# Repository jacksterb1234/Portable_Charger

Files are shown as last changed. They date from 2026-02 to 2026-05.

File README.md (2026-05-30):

# Portable Charger — USB-C Power Delivery PCB

A custom portable USB-C Power Delivery (PD) charger with a dedicated PD trigger circuit for negotiating output voltage. Powered from a single USB-C input and designed for compact, portable use.

## Features

- **USB-C Power Delivery** input with PD voltage negotiation trigger
- **Custom PD trigger circuit** to request a specific voltage from the source
- Compact KiCad PCB design optimized for portability
- Designed with **JLCPCB assembly** constraints in mind
- CAD enclosure files included

## Repository Structure

```
Portable_Charger/
├── Charger_Kicad/         # Main charger PCB KiCad project
├── USBC_PD_Trigger_Kicad/ # USB-C PD trigger board KiCad project
└── CAD/                   # Enclosure / mechanical CAD files
```

## How It Works

1. The **PD trigger board** negotiates a target voltage with a USB-C PD source using the CC lines
2. The negotiated voltage is passed to the **charger board** for regulation and output
3. The design runs entirely from a single USB-C cable — no barrel jacks or separate power supplies required

## Tools Used

- **KiCad** — Schematic capture and PCB layout
- **JLCPCB** — PCB fabrication and assembly
- **Fusion360 / SolidWorks** — Enclosure design

## Author

**Jackson Barber** — [github.com/jacksterb1234](https://github.com/jacksterb1234)

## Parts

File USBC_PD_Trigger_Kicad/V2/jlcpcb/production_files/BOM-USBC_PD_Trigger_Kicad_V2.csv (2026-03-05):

Comment | Designator | Footprint | LCSC | Quantity
100nF | C1,C5,C8 | C_0805 | C28233 | 3
10kΩ | R10,R6,R8 | R_0805 | C17414 | 3
10nF | C9 | C_0805 | C1710 | 1
10uF | C12,C13,C2 | C_0805 | C15850 | 3
1uF | C10,C4 | C_0805 | C28323 | 2
200kΩ | R9 | R_0805 | C17539 | 1
22uF | C3 | C_0805 | C45783 | 1
300Ω | R11,R12,R13,R14 | R_0805 | C17617 | 4
4.7kΩ | R1,R2,R3,RPA0 | R_0805 | C17673 | 4
4.7uF | C11 | C_0805 | C1779 | 1
470pF | C6,C7 | C_0805 | C1743 | 2
8.2kΩ | R7 | R_0805 | C17828 | 1
ATtiny816-S | U4 | SOIC-20W_7.5x12.8mm_P1.27mm | C2054204 | 1
FUSB302BMPX | U1 | WQFN-14-1EP_2.5x2.5mm_P0.5mm_EP1.45x1.45mm | C132291 | 1
HT7533 | U2 | SOT-89-3_L4.5-W2.5-P1.50-LS4.2-BR | C14289 | 1
LED | D5 | LED_0805_2012Metric | C2297 | 1
LS2406ERQ23 | U3 | QFN16L_2P5X3P2-0P6_LTF | C5355481 | 1
Screw_Terminal_01x02 | J2 | TerminalBlock_RND_205-00045_1x02_P5.00mm_Horizontal | C3703 | 1
Tactile Button, 160gf | S1 | SW_TS-1088-AR02016 | C720477 | 1
USB_C_Receptacle_PowerOnly_6P | J1 | USB_C_Receptacle_GCT_USB4125-xx-x-0190_6P_TopMnt_Horizontal | C7507406 | 1
Conn_01x03_Pin | J3 | PinHeader_1x03_P2.54mm_Vertical |  | 1
LED | D7 | LED_0805_2012Metric |  | 1
LED | D8 | LED_0805_2012Metric |  | 1
LED | D6 | LED_0805_2012Metric |  | 1

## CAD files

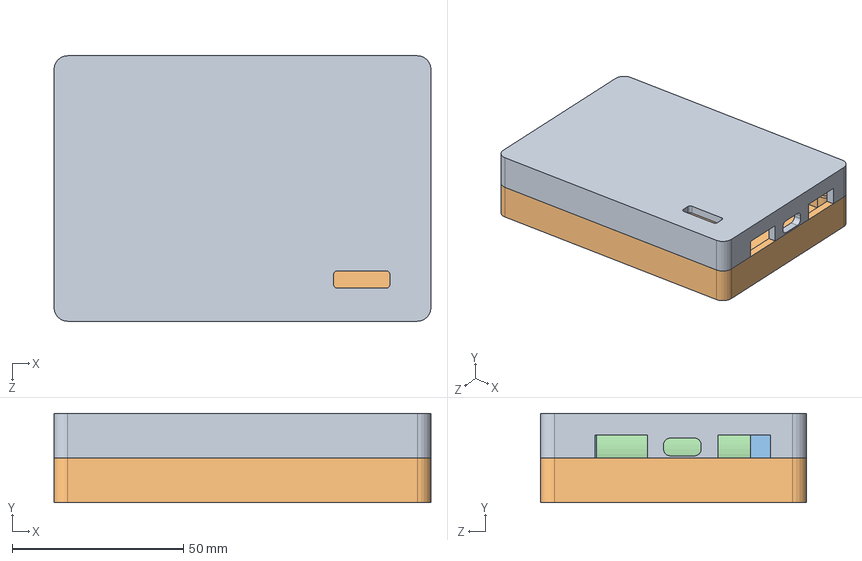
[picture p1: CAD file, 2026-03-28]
CAD/Charger_Main.SLDASM
110.0 x 26.0 x 77.5 mm
Battery_Cell x 3
6S_Battery_Holder x 2
Charger_Case
Charger_Case_Top

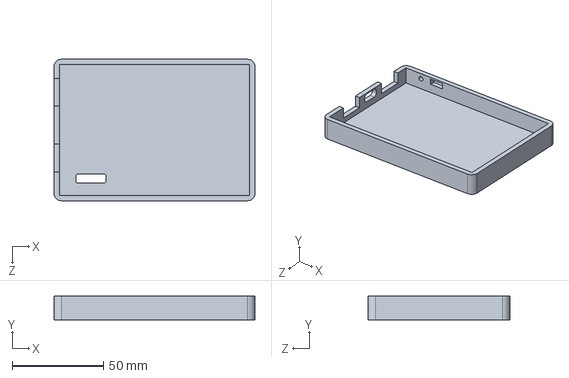
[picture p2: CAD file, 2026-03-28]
CAD/Charger_Case_Top.SLDPRT
110.0 x 13.0 x 77.5 mm

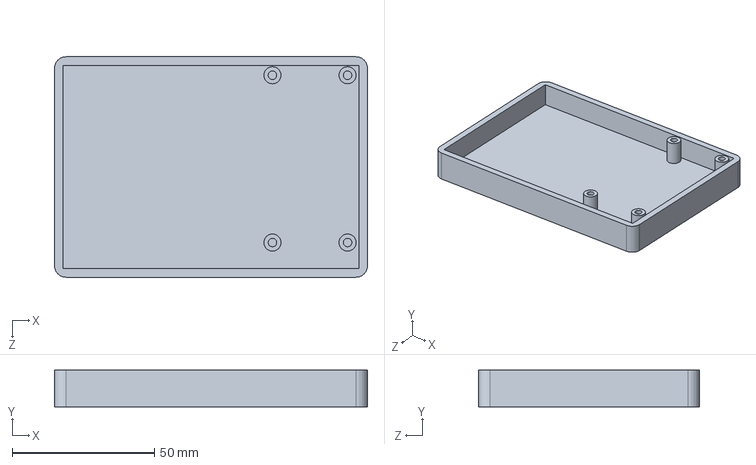
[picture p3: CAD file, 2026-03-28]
CAD/Charger_Case.SLDPRT
110.0 x 13.0 x 77.5 mm

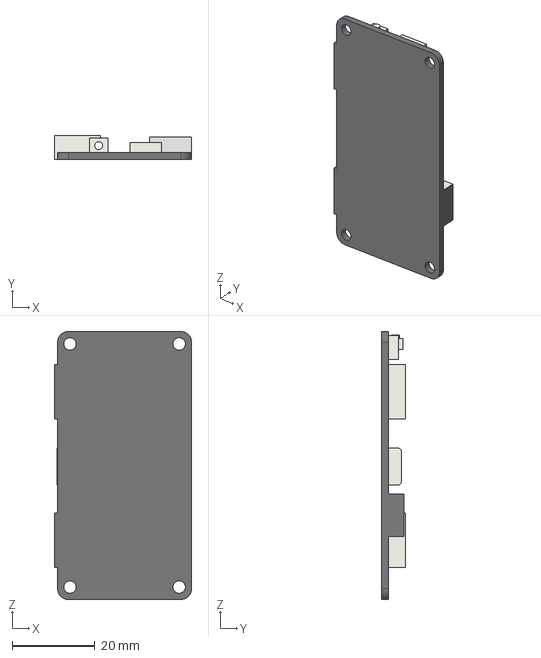
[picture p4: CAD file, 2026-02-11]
CAD/IP5328P.step
33.2 x 5.73 x 64.8 mm

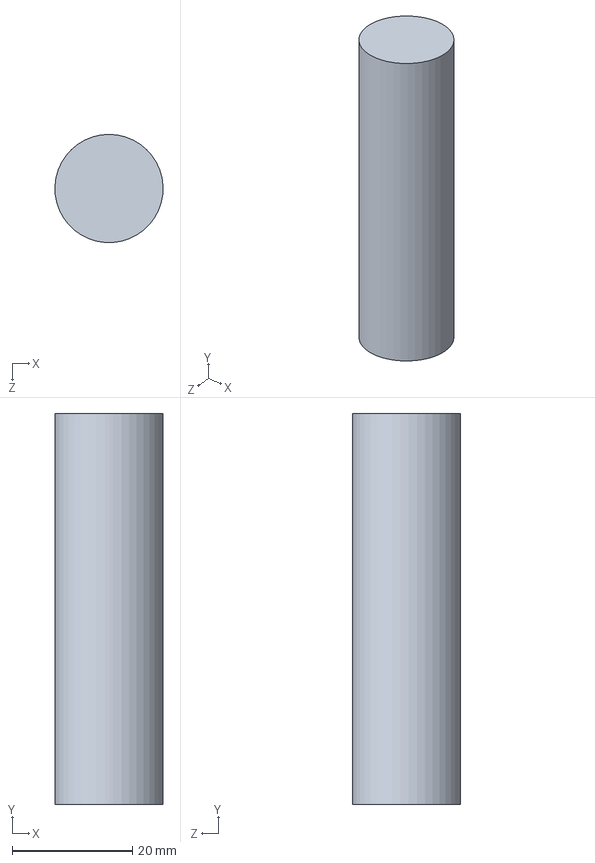
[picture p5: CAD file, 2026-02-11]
CAD/Battery_Cell.SLDPRT
18.0 x 65.0 x 18.0 mm

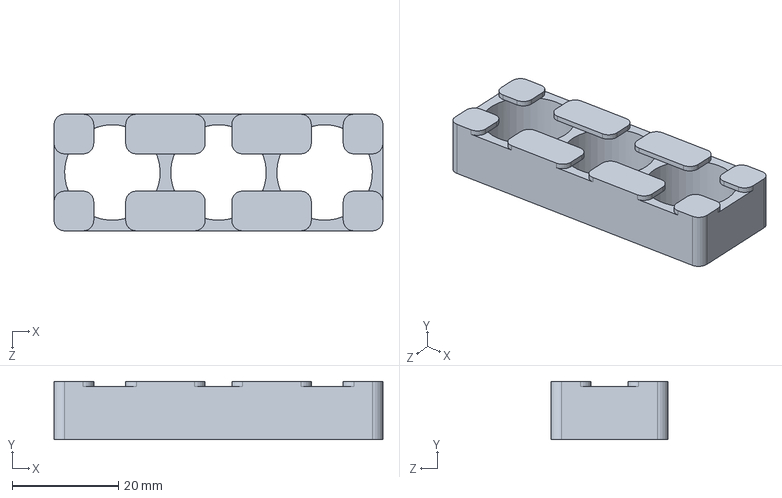
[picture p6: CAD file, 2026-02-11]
CAD/6S_Battery_Holder.SLDPRT
62.0 x 11.0 x 22.0 mm

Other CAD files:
CAD/6S_Battery_Holder.STL
CAD/Charger_Case.STL
CAD/Charger_Case_Top.STL

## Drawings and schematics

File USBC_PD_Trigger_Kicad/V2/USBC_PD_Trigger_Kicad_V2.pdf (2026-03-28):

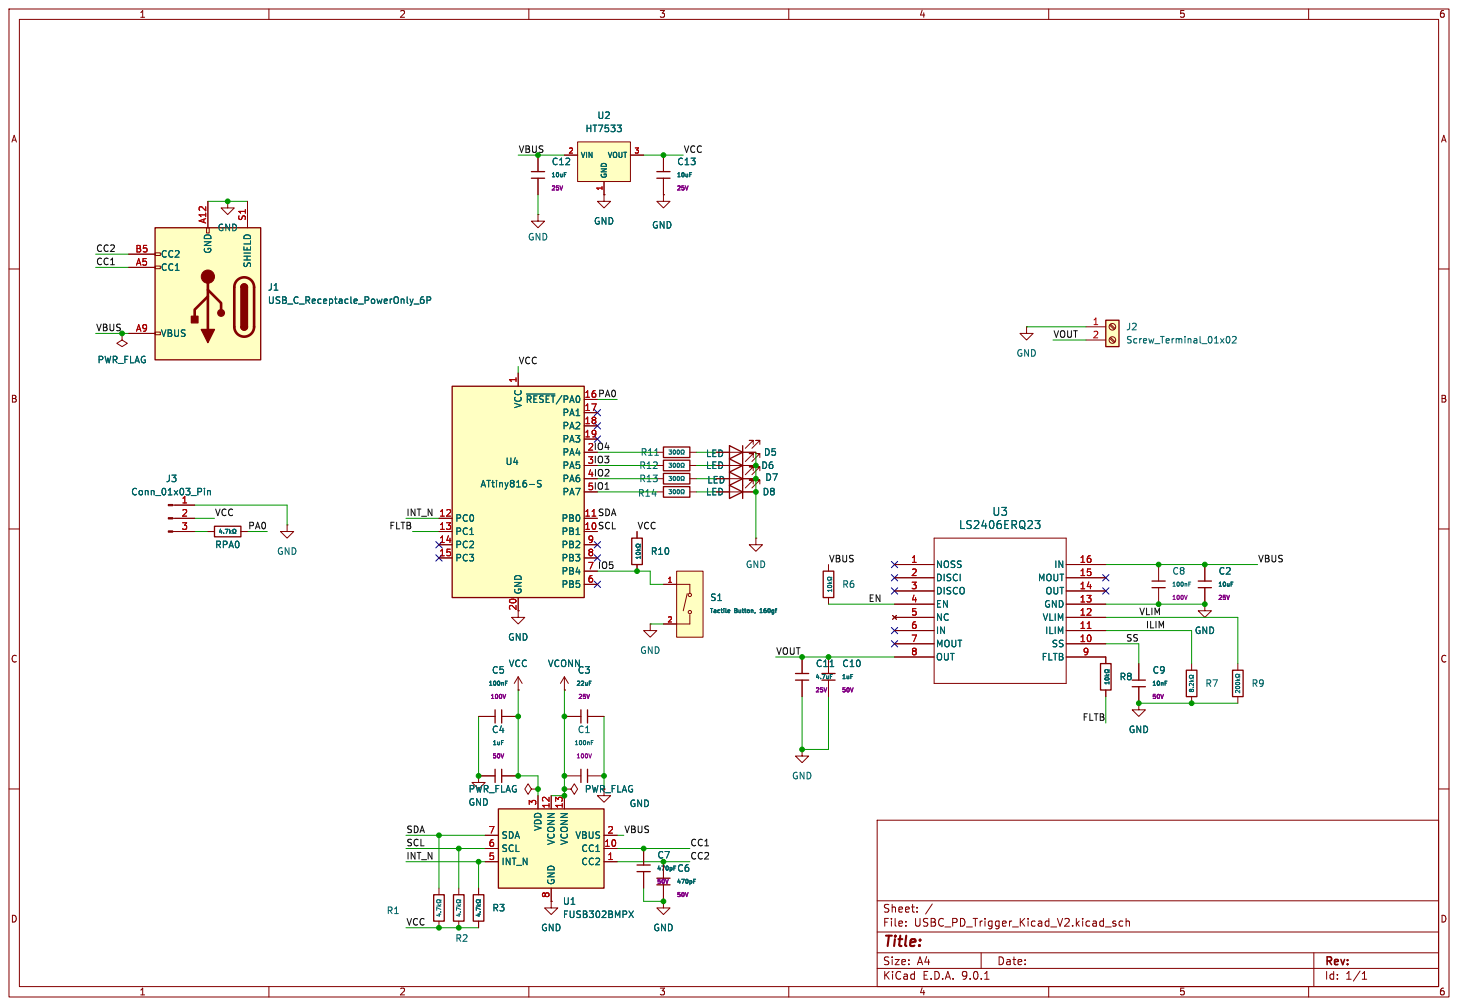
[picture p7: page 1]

8 VCONN 13 VBUS 2 CC1 10 CC2 1 U1 FUSB302BMPX NOSS 1 DISCI 2 DISCO 3 EN 4 NC 5

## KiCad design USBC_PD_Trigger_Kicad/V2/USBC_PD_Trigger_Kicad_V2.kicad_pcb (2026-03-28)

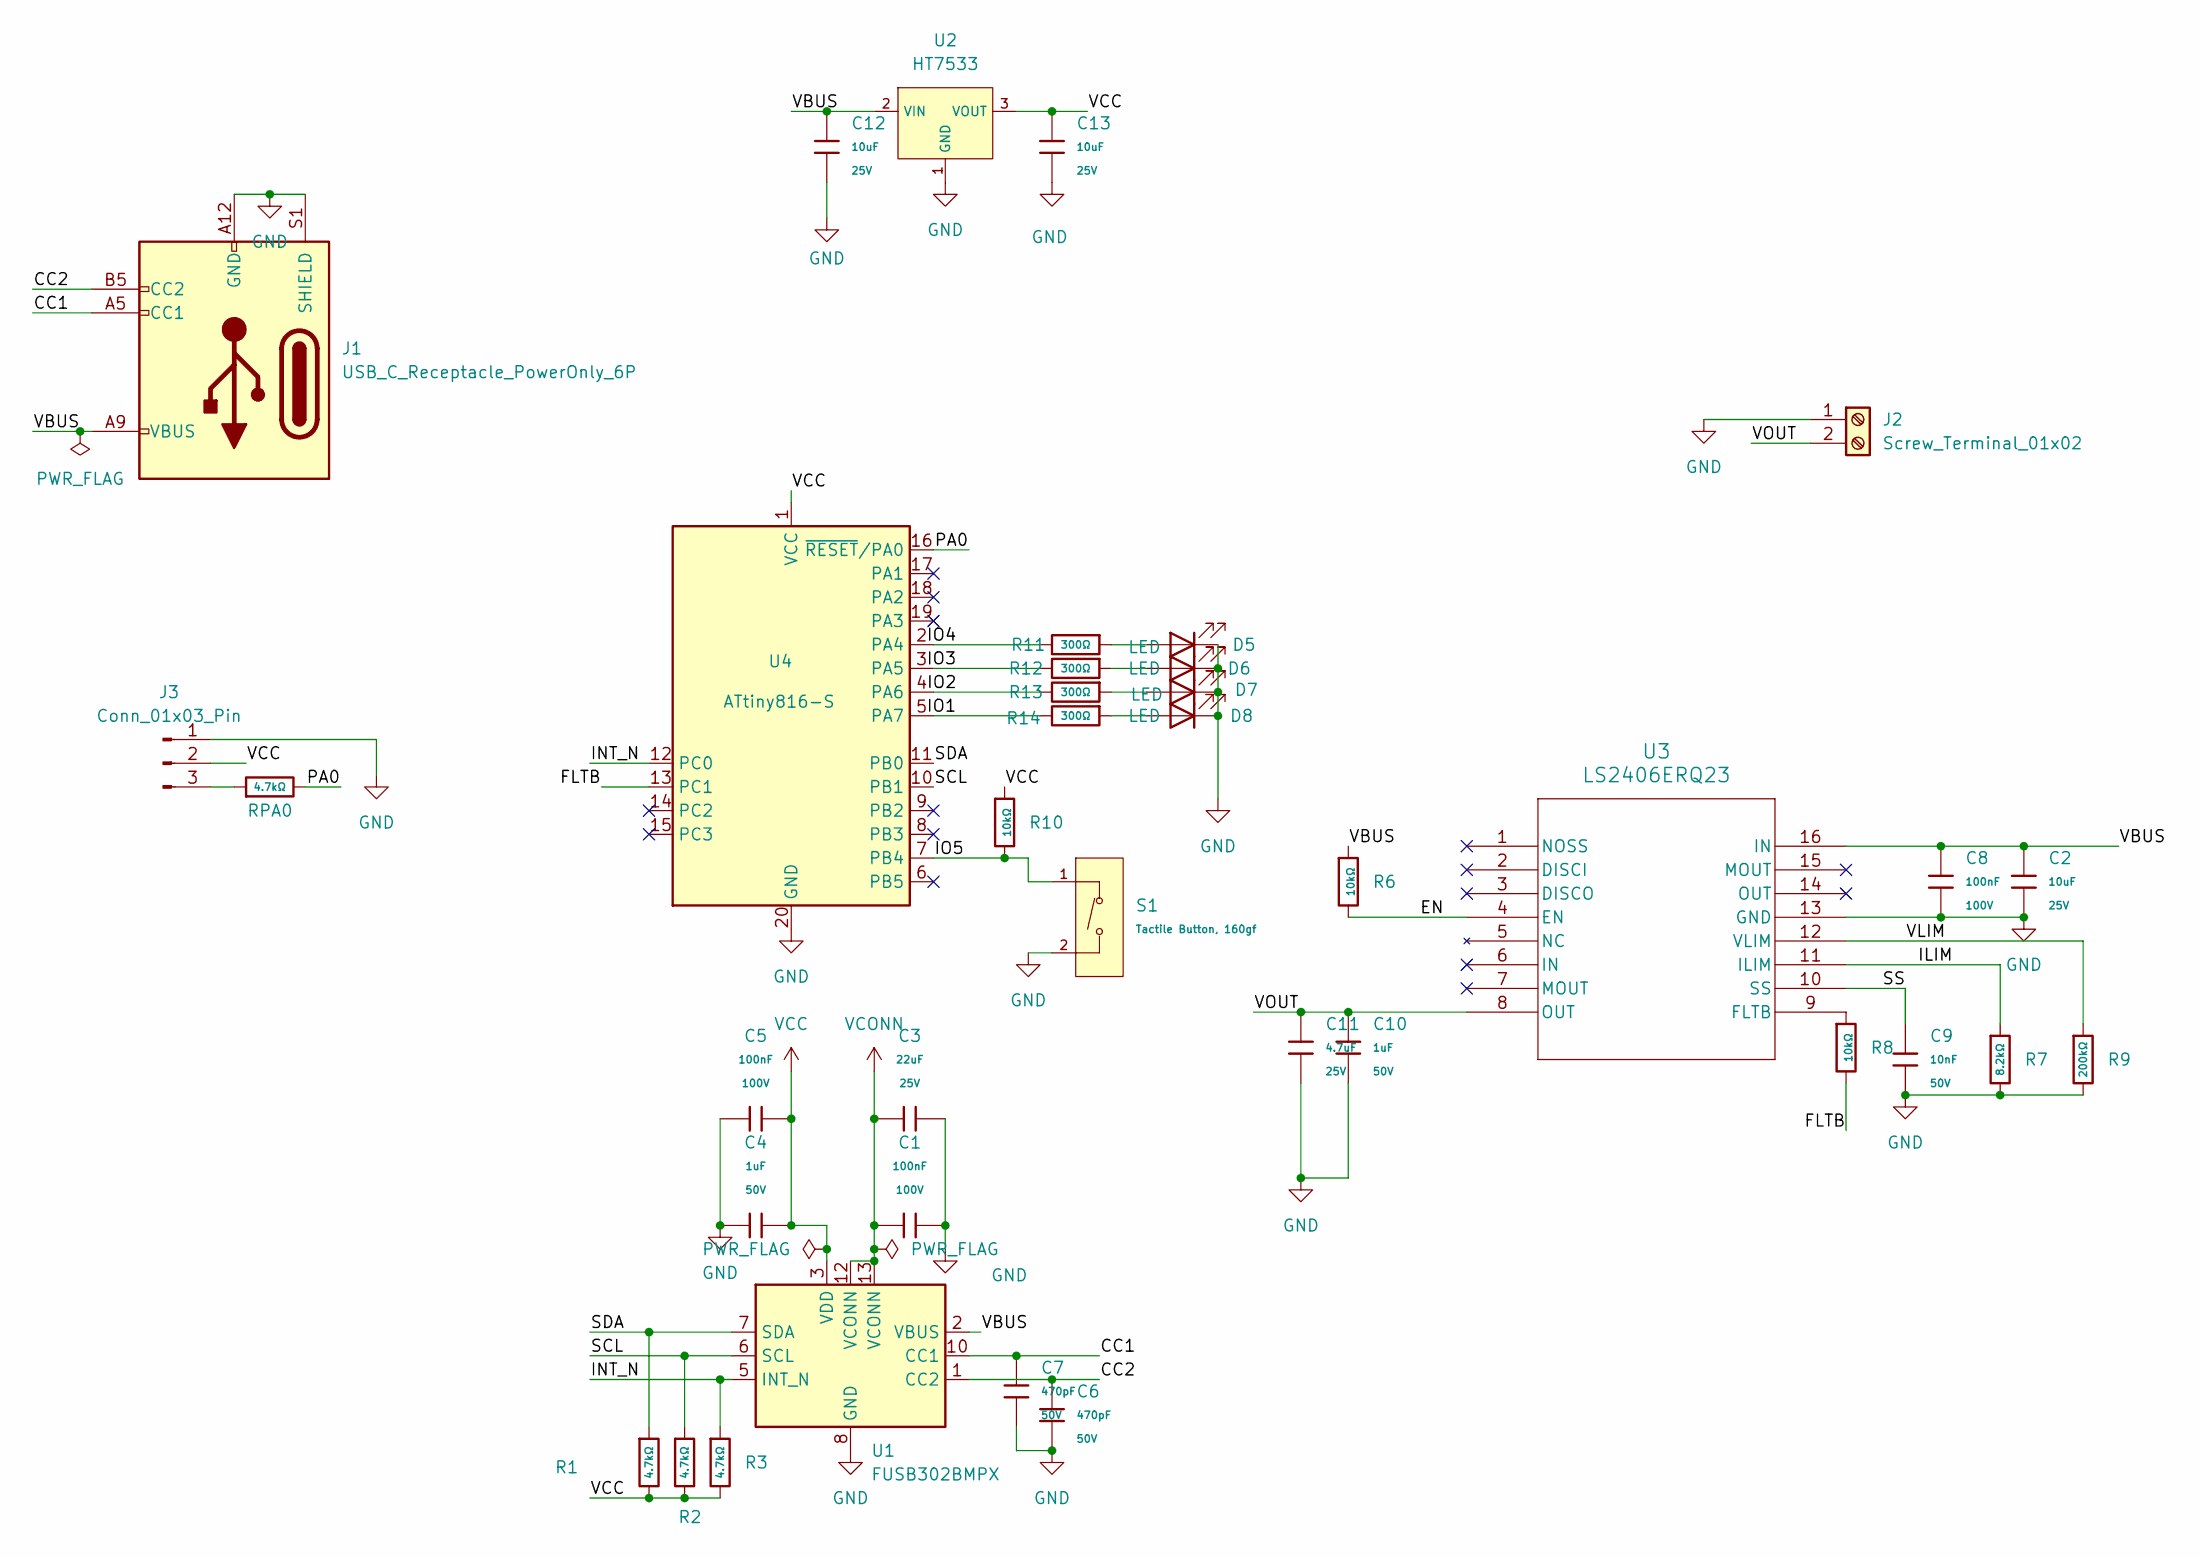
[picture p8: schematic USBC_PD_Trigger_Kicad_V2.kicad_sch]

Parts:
C1, C5, C8: 100nF; C_0805; Voltage Rated 100V; Tolerance ±10%; Part CL21B104KCFNNNE; LCSC C28233
C2, C12, C13: 10uF; C_0805; Voltage Rated 25V; Tolerance ±10%; Part CL21A106KAYNNNE; LCSC C15850
C3: 22uF; C_0805; Voltage Rated 25V; Tolerance ±20%; Part CL21A226MAQNNNE; LCSC C45783
C4, C10: 1uF; C_0805; Voltage Rated 50V; Tolerance ±10%; Part CL21B105KBFNNNE; LCSC C28323
C6, C7: 470pF; C_0805; Voltage Rated 50V; Tolerance ±10%; Part 0805B471K500NT; LCSC C1743
C9: 10nF; C_0805; Voltage Rated 50V; Tolerance ±10%; Part CL21B103KBANNNC; LCSC C1710
C11: 4.7uF; C_0805; Voltage Rated 25V; Tolerance ±10%; Part CL21A475KAQNNNE; LCSC C1779
D5, D6, D7, D8: LED; LED_0805_2012Metric
J1: USB_C_Receptacle_PowerOnly_6P; USB_C_Receptacle_GCT_USB4125-xx-x-0190_6P_TopMnt_Horizontal
J2: Screw_Terminal_01x02; TerminalBlock_RND_205-00045_1x02_P5.00mm_Horizontal
J3: Conn_01x03_Pin; PinHeader_1x03_P2.54mm_Vertical
R1, R2, R3: 4.7kΩ; R_0805; Overload Voltage (Max) 150V; Tolerance ±1%; Part 0805W8F4701T5E; LCSC C17673
R6, R8, R10: 10kΩ; R_0805; Overload Voltage (Max) 150V; Tolerance ±1%; Part 0805W8F1002T5E; LCSC C17414
R7: 8.2kΩ; R_0805; Overload Voltage (Max) 150V; Tolerance ±1%; Part 0805W8F8201T5E; LCSC C17828
R9: 200kΩ; R_0805; Overload Voltage (Max) 150V; Tolerance ±1%; Part 0805W8F2003T5E; LCSC C17539
R11, R12, R13, R14: 300Ω; R_0805; Overload Voltage (Max) 150V; Tolerance ±1%; Part 0805W8F3000T5E; LCSC C17617
RPA0: 4.7kΩ; R_0805; Overload Voltage (Max) 150V; Tolerance ±1%; Part 0805W8F4701T5E; LCSC C17673
S1: Tactile Button, 160gf; SW_TS-1088-AR02016; Voltage Rating (Dc) 12V; Part TS-1088-AR02016; LCSC C720477
U1: FUSB302BMPX; WQFN-14-1EP_2.5x2.5mm_P0.5mm_EP1.45x1.45mm
U2: HT7533; SOT-89-3_L4.5-W2.5-P1.50-LS4.2-BR; Output Voltage 3.3V; Dropout Voltage 55mV@(1mA); Part HT7533-1; LCSC C14289
U3: LS2406ERQ23; QFN16L_2P5X3P2-0P6_LTF
U4: ATtiny816-S; SOIC-20W_7.5x12.8mm_P1.27mm

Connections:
/CC1: C7.1, J1.A5 (CC1), U1.10 (CC1), U1.11 (CC1)
/CC2: C6.1, J1.B5 (CC2), U1.1 (CC2), U1.14 (CC2)
/EN: R6.2, U3.4 (EN)
/FLTB: R8.2, U4.13 (PC1)
/ILIM: R7.1, U3.11 (ILIM)
/INT_N: R3.1, U1.5 (INT_N), U4.12 (PC0)
/IO1: R14.2, U4.5 (PA7)
/IO2: R13.2, U4.4 (PA6)
/IO3: R12.2, U4.3 (PA5)
/IO4: R11.2, U4.2 (PA4)
/IO5: R10.2, S1.1 (A), U4.7 (PB4)
/PA0: RPA0.2, U4.16 (~RESET/PA0)
/SCL: R2.1, U1.6 (SCL), U4.10 (PB1)
/SDA: R1.1, U1.7 (SDA), U4.11 (PB0)
/SS: C9.1, U3.10 (SS)
/VBUS: C2.1, C8.1, C12.1, J1.A9 (VBUS), J1.B9 (VBUS), R6.1, U1.2 (VBUS), U2.2 (VIN), U3.16 (IN)
/VLIM: R9.1, U3.12 (VLIM)
/VOUT: C10.1, C11.1, J2.2, U3.8 (OUT)
GND: C1.2, C2.2, C3.2, C4.1, C5.2, C6.2, C7.2, C8.2, C9.2, C10.2, C11.2, C12.2, C13.2, D5.1 (K), D6.1 (K), D7.1 (K), D8.1 (K), J1.A12 (GND), J1.B12 (GND), J1.S1 (SHIELD), J2.1, J3.1, R7.2, R9.2, S1.2 (B), U1.8 (GND), U1.9 (GND), U1.15 (GND), U2.1 (GND), U3.13 (GND), U4.20 (GND)
unnamed: D5.2 (A), R11.1
unnamed: D6.2 (A), R12.1
unnamed: D7.2 (A), R13.1
unnamed: D8.2 (A), R14.1
unnamed: J3.3, RPA0.1
unnamed: R8.1, U3.9 (FLTB)
VCC: C4.2, C5.1, C13.1, J3.2, R1.2, R2.2, R3.2, R10.1, U1.3 (VDD), U1.4 (VDD), U2.3 (VOUT), U4.1 (VCC)
VCONN: C1.1, C3.1, U1.12 (VCONN), U1.13 (VCONN)

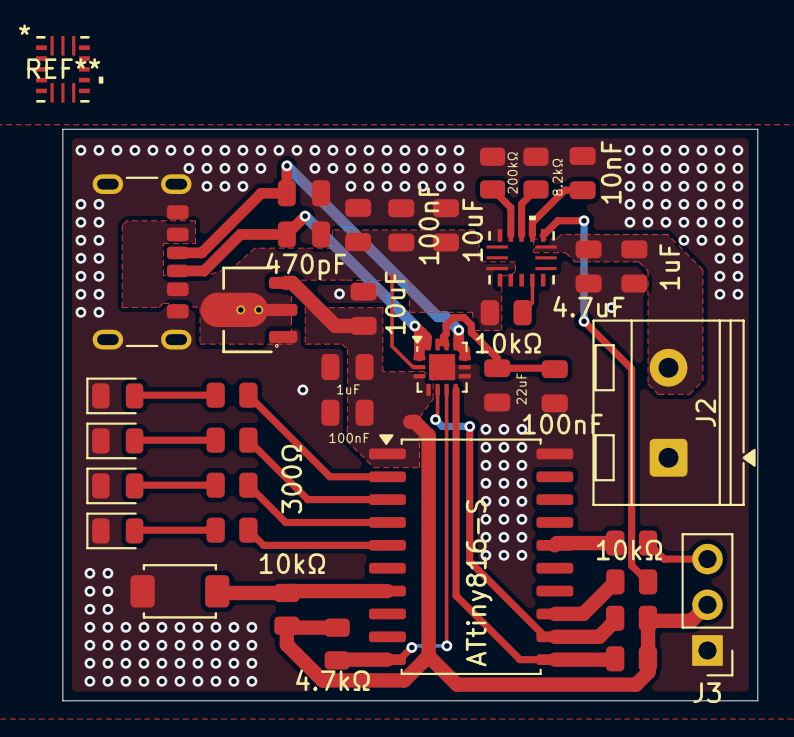
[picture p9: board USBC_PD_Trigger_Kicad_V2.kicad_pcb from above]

Board: 2 copper layers, 38.6 x 31.7 mm, 38 parts (0 on the bottom side), 27 nets.

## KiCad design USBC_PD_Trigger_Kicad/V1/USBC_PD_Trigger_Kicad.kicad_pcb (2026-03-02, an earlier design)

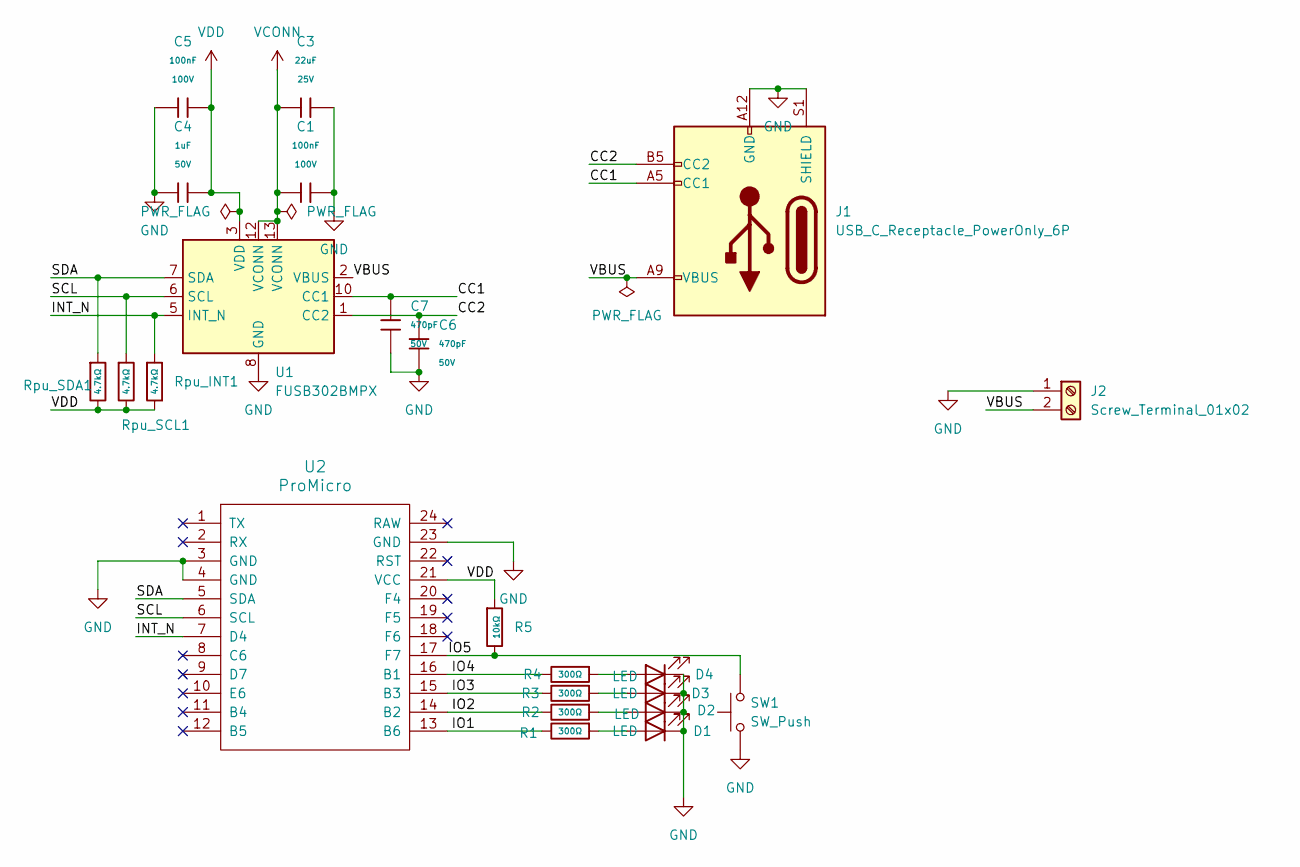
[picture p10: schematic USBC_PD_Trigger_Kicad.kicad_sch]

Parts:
C1, C5: 100nF; C_0805; Voltage Rated 100V; Tolerance ±10%; Part CL21B104KCFNNNE; LCSC C28233
C3: 22uF; C_0805; Voltage Rated 25V; Tolerance ±20%; Part CL21A226MAQNNNE; LCSC C45783
C4: 1uF; C_0805; Voltage Rated 50V; Tolerance ±10%; Part CL21B105KBFNNNE; LCSC C28323
C6, C7: 470pF; C_0805; Voltage Rated 50V; Tolerance ±10%; Part 0805B471K500NT; LCSC C1743
D1, D2, D3, D4: LED; LED_0805_2012Metric
J1: USB_C_Receptacle_PowerOnly_6P; USB_C_Receptacle_GCT_USB4125-xx-x-0190_6P_TopMnt_Horizontal
J2: Screw_Terminal_01x02; TerminalBlock_RND_205-00045_1x02_P5.00mm_Horizontal
R1, R2, R3, R4: 300Ω; R_0805; Overload Voltage (Max) 150V; Tolerance ±1%; Part 0805W8F3000T5E; LCSC C17617
R5: 10kΩ; R_0805; Overload Voltage (Max) 150V; Tolerance ±1%; Part 0805W8F1002T5E; LCSC C17414
Rpu_INT1: 4.7kΩ; R_0805; Overload Voltage (Max) 150V; Tolerance ±1%; Part 0805W8F4701T5E; LCSC C17673
Rpu_SCL1: 4.7kΩ; R_0805; Overload Voltage (Max) 150V; Tolerance ±1%; Part 0805W8F4701T5E; LCSC C17673
Rpu_SDA1: 4.7kΩ; R_0805; Overload Voltage (Max) 150V; Tolerance ±1%; Part 0805W8F4701T5E; LCSC C17673
SW1: SW_Push; SW_SPST_PTS645
U1: FUSB302BMPX; WQFN-14-1EP_2.5x2.5mm_P0.5mm_EP1.45x1.45mm
U2: ProMicro

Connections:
/CC1: C7.1, J1.A5 (CC1), U1.10 (CC1), U1.11 (CC1)
/CC2: C6.1, J1.B5 (CC2), U1.1 (CC2), U1.14 (CC2)
/INT_N: Rpu_INT1.1, U1.5 (INT_N), U2.7 (D4)
/IO1: R1.2, U2.13 (B6)
/IO2: R2.2, U2.14 (B2)
/IO3: R3.2, U2.15 (B3)
/IO4: R4.2, U2.16 (B1)
/IO5: R5.2, SW1.2, U2.17 (F7)
/SCL: Rpu_SCL1.1, U1.6 (SCL), U2.6 (SCL)
/SDA: Rpu_SDA1.1, U1.7 (SDA), U2.5 (SDA)
/VBUS: J1.A9 (VBUS), J1.B9 (VBUS), J2.2, U1.2 (VBUS)
GND: C1.2, C3.2, C4.1, C5.2, C6.2, C7.2, D1.1 (K), D2.1 (K), D3.1 (K), D4.1 (K), J1.A12 (GND), J1.B12 (GND), J1.S1 (SHIELD), J2.1, SW1.1, U1.8 (GND), U1.9 (GND), U1.15 (GND), U2.3 (GND), U2.4 (GND), U2.23 (GND)
unnamed: D1.2 (A), R1.1
unnamed: D2.2 (A), R2.1
unnamed: D3.2 (A), R3.1
unnamed: D4.2 (A), R4.1
VCONN: C1.1, C3.1, U1.12 (VCONN), U1.13 (VCONN)
VDD: C4.2, C5.1, R5.1, Rpu_INT1.2, Rpu_SCL1.2, Rpu_SDA1.2, U1.3 (VDD), U1.4 (VDD), U2.21 (VCC)

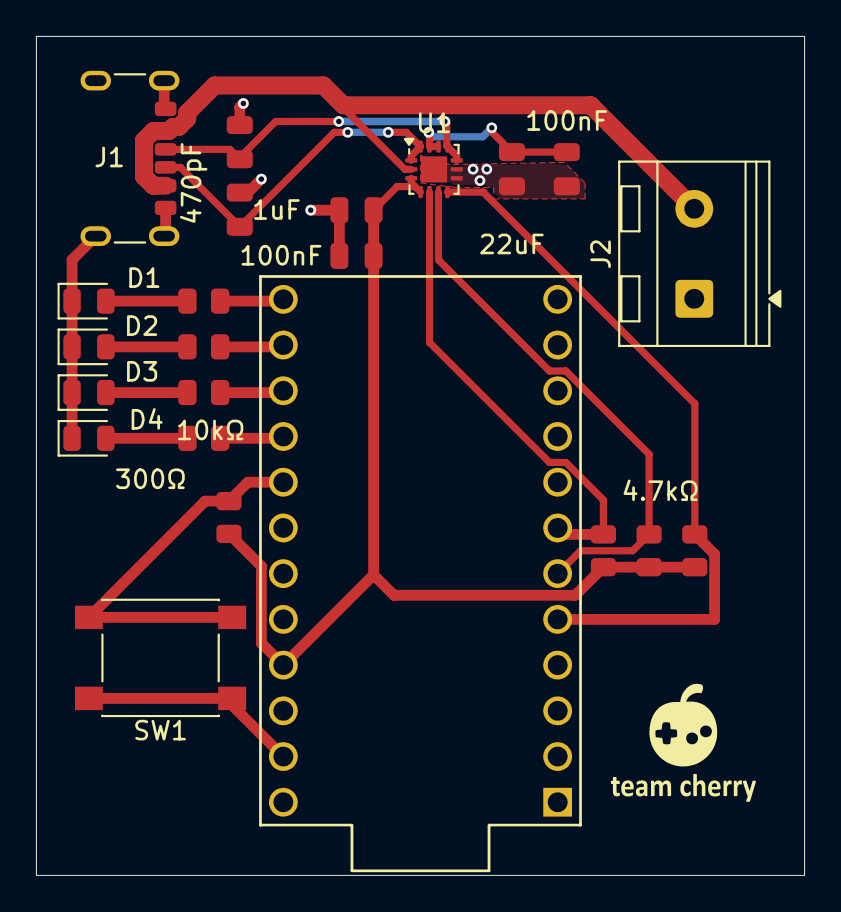
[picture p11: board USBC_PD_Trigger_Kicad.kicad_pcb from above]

Board: 2 copper layers, 42.7 x 46.6 mm, 23 parts (0 on the bottom side), 18 nets.

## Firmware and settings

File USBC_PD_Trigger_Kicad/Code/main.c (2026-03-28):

// USB-C PD Trigger - ATtiny816 + FUSB302B Firmware
// Minimal, functional implementation
#define F_CPU 20000000UL
#include <avr/io.h>
#include <util/delay.h>
#include <avr/interrupt.h>
#include <stdbool.h>
#include <stdint.h>

// ========== PIN ASSIGNMENTS ==========
#define LED_PORT         PORTA
#define LED_DDR          DDRA
#define LED_PIN_1        PA7
#define LED_PIN_2        PA6
#define LED_PIN_3        PA5
#define LED_PIN_4        PA4
#define LED_MASK         ((1<<PA7)|(1<<PA6)|(1<<PA5)|(1<<PA4))

#define BUTTON_PORT      PORTB
#define BUTTON_PIN_REG   PINB
#define BUTTON_DDR       DDRB
#define BUTTON_PIN       PB4

#define FLTB_PORT        PORTC
#define FLTB_PIN_REG     PINC
#define FLTB_DDR         DDRC
#define FLTB_PIN         PC1

#define FUSB_INT_PORT    PORTC
#define FUSB_INT_PIN_REG PINC
#define FUSB_INT_DDR     DDRC
#define FUSB_INT_PIN     PC0

#define I2C_SCL_PORT     PORTB
#define I2C_SCL_PIN_REG  PINB
#define I2C_SCL_DDR      DDRB
#define I2C_SCL_PIN      PB1

#define I2C_SDA_PORT     PORTB
#define I2C_SDA_PIN_REG  PINB
#define I2C_SDA_DDR      DDRB
#define I2C_SDA_PIN      PB0

// ========== FUSB302B REGISTERS ==========
#define FUSB_ADDR           0x44    // I2C write address (0x22 << 1)
#define FUSB_REG_DEVICE_ID  0x01
#define FUSB_REG_SWITCHES0  0x02
#define FUSB_REG_SWITCHES1  0x03
#define FUSB_REG_MEASURE    0x04
#define FUSB_REG_SLICE      0x05
#define FUSB_REG_CONTROL0   0x06
#define FUSB_REG_CONTROL1   0x07
#define FUSB_REG_CONTROL2   0x08
#define FUSB_REG_CONTROL3   0x09
#define FUSB_REG_MASK       0x0A
#define FUSB_REG_POWER      0x0B
#define FUSB_REG_RESET      0x0C
#define FUSB_REG_OCPREG     0x0D
#define FUSB_REG_MASKA      0x0E
#define FUSB_REG_MASKB      0x0F
#define FUSB_REG_CONTROL4   0x10
#define FUSB_REG_STATUS0    0x40
#define FUSB_REG_STATUS1    0x41
#define FUSB_REG_INTERRUPT  0x42
#define FUSB_REG_INTERRUPTB 0x43
#define FUSB_REG_FIFO       0x43

// ========== STATE MACHINE & GLOBALS ==========
#define N_VOLTAGES    4
static const uint16_t target_voltages[N_VOLTAGES] = {5000, 9000, 15000, 20000};
static uint8_t current_voltage_idx = 0;
static uint8_t negotiated_voltage_idx = 0;

static volatile bool button_pressed = false;
static volatile bool button_release = false;
static volatile bool fusb_interrupt = false;
static volatile bool fault_detected = false;

static uint32_t last_pdo_rx = 0;
static uint8_t last_source_caps[30];
static uint8_t last_source_caps_len = 0;

// ========== I2C BITBANG IMPLEMENTATION ==========
static inline void i2c_scl_release(void) {
    I2C_SCL_DDR &= ~(1 << I2C_SCL_PIN);  // float high (open-drain)
}
static inline void i2c_scl_pull(void) {
    I2C_SCL_DDR |= (1 << I2C_SCL_PIN);   // pull low
    I2C_SCL_PORT &= ~(1 << I2C_SCL_PIN);
}
static inline void i2c_sda_release(void) {
    I2C_SDA_DDR &= ~(1 << I2C_SDA_PIN);
}
static inline void i2c_sda_pull(void) {
    I2C_SDA_DDR |= (1 << I2C_SDA_PIN);
    I2C_SDA_PORT &= ~(1 << I2C_SDA_PIN);
}

static void i2c_init(void) {
    i2c_scl_release();
    i2c_sda_release();
    _delay_us(10);
}

static void i2c_start(void) {
    i2c_sda_release();
    i2c_scl_release();
    _delay_us(5);
    i2c_sda_pull();     // SDA low while SCL high = START
    _delay_us(5);
    i2c_scl_pull();
    _delay_us(5);
}

static void i2c_stop(void) {
    i2c_sda_pull();
    i2c_scl_release();
    _delay_us(5);
    i2c_sda_release();  // SDA high while SCL high = STOP
    _delay_us(5);
}

static void i2c_write_bit(uint8_t bit) {
    if (bit) i2c_sda_release();
    else i2c_sda_pull();
    _delay_us(3);
    i2c_scl_release();
    _delay_us(5);
    i2c_scl_pull();
    _delay_us(3);
}

static uint8_t i2c_read_bit(void) {
    i2c_sda_release();
    _delay_us(3);
    i2c_scl_release();
    _delay_us(5);
    uint8_t bit = (I2C_SDA_PIN_REG & (1 << I2C_SDA_PIN)) ? 1 : 0;
    i2c_scl_pull();
    _delay_us(3);
    return bit;
}

static bool i2c_write_byte(uint8_t byte) {
    for (int8_t i = 7; i >= 0; i--) {
        i2c_write_bit((byte >> i) & 1);
    }
    uint8_t ack = !i2c_read_bit();  // ACK = SDA pulled low by slave
    return ack;
}

static uint8_t i2c_read_byte(bool ack) {
    uint8_t byte = 0;
    for (int8_t i = 7; i >= 0; i--) {
        byte = (byte << 1) | i2c_read_bit();
    }
    i2c_write_bit(!ack);  // send ACK or NAK
    return byte;
}

// ========== FUSB302B REGISTER ACCESS ==========
static bool fusb_write_reg(uint8_t reg, uint8_t value) {
    i2c_start();
    if (!i2c_write_byte(FUSB_ADDR)) { i2c_stop(); return false; }
    if (!i2c_write_byte(reg)) { i2c_stop(); return false; }
    if (!i2c_write_byte(value)) { i2c_stop(); return false; }
    i2c_stop();
    _delay_us(50);
    return true;
}

static bool fusb_read_reg(uint8_t reg, uint8_t *value) {
    i2c_start();
    if (!i2c_write_byte(FUSB_ADDR)) { i2c_stop(); return false; }
    if (!i2c_write_byte(reg)) { i2c_stop(); return false; }
    i2c_start();
    if (!i2c_write_byte(FUSB_ADDR | 1)) { i2c_stop(); return false; }
    *value = i2c_read_byte(false);
    i2c_stop();
    _delay_us(50);
    return true;
}

static bool fusb_write_block(uint8_t reg, const uint8_t *data, uint8_t len) {
    i2c_start();
    if (!i2c_write_byte(FUSB_ADDR)) { i2c_stop(); return false; }
    if (!i2c_write_byte(reg)) { i2c_stop(); return false; }
    for (uint8_t i = 0; i < len; i++) {
        if (!i2c_write_byte(data[i])) { i2c_stop(); return false; }
    }
    i2c_stop();
    _delay_us(50);
    return true;
}

static bool fusb_read_block(uint8_t reg, uint8_t *data, uint8_t len) {
    i2c_start();
    if (!i2c_write_byte(FUSB_ADDR)) { i2c_stop(); return false; }
    if (!i2c_write_byte(reg)) { i2c_stop(); return false; }
    i2c_start();
    if (!i2c_write_byte(FUSB_ADDR | 1)) { i2c_stop(); return false; }
    for (uint8_t i = 0; i < len; i++) {
        data[i] = i2c_read_byte(i < (len - 1));
    }
    i2c_stop();
    _delay_us(50);
    return true;
}

// ========== FUSB302B INITIALIZATION ==========
static bool fusb_init(void) {
    uint8_t dev_id = 0;
    if (!fusb_read_reg(FUSB_REG_DEVICE_ID, &dev_id)) return false;
    
    // Soft reset
    if (!fusb_write_reg(FUSB_REG_RESET, 0x01)) return false;
    _delay_ms(5);
    
    // POWER register: enable oscillator
    if (!fusb_write_reg(FUSB_REG_POWER, 0x0F)) return false;
    
    // SWITCHES0: enable all muxes for CC detection
    if (!fusb_write_reg(FUSB_REG_SWITCHES0, 0x07)) return false;
    
    // SWITCHES1: power down VCONN
    if (!fusb_write_reg(FUSB_REG_SWITCHES1, 0x00)) return false;
    
    // MEASURE: measure CC1 and CC2
    if (!fusb_write_reg(FUSB_REG_MEASURE, 0x00)) return false;
    
    // SLICE: set threshold
    if (!fusb_write_reg(FUSB_REG_SLICE, 0x20)) return false;
    
    // CONTROL0: enable source mode, look for connection
    if (!fusb_write_reg(FUSB_REG_CONTROL0, 0x04)) return false;
    
    // CONTROL1: enable PD
    if (!fusb_write_reg(FUSB_REG_CONTROL1, 0x04)) return false;
    
    // CONTROL2: force sink off
    if (!fusb_write_reg(FUSB_REG_CONTROL2, 0x00)) return false;
    
    // CONTROL3: send GoodCRC
    if (!fusb_write_reg(FUSB_REG_CONTROL3, 0x06)) return false;
    
    // MASK: Interrupt mask
    if (!fusb_write_reg(FUSB_REG_MASK, 0xFF)) return false;
    if (!fusb_write_reg(FUSB_REG_MASKA, 0xFF)) return false;
    if (!fusb_write_reg(FUSB_REG_MASKB, 0xFF)) return false;
    
    return true;
}

// ========== PD REQUESTS ==========
static uint32_t build_rdo(uint8_t obj_pos, uint32_t max_current_ma, uint32_t operating_current_ma, uint8_t capability_mismatch) {
    return ((obj_pos & 0x7) << 28) | 
           ((capability_mismatch & 1) << 26) |
           (((max_current_ma / 10) & 0x3FF) << 10) |
           ((operating_current_ma / 10) & 0x3FF);
}

static bool fusb_send_request(uint8_t voltage_idx) {
    if (voltage_idx >= N_VOLTAGES) return false;
    return true;
}

// ========== LED CONTROL ==========
static void leds_init(void) {
    LED_DDR |= LED_MASK;
    LED_PORT &= ~LED_MASK;
}

static void leds_set(uint8_t voltage_idx) {
    if (voltage_idx >= N_VOLTAGES) voltage_idx = 0;
    
    uint8_t mask = 0;
    for (uint8_t i = 0; i <= voltage_idx; i++) {
        mask |= (1 << (PA7 - i));
    }
    LED_PORT = (LED_PORT & ~LED_MASK) | (mask & LED_MASK);
}

static void leds_flash(uint8_t count, uint16_t delay_ms) {
    for (uint8_t i = 0; i < count; i++) {
        LED_PORT |= LED_MASK;
        _delay_ms(delay_ms);
        LED_PORT &= ~LED_MASK;
        _delay_ms(delay_ms);
    }
}

// ========== BUTTON & INPUT HANDLERS ==========
static void button_init(void) {
    BUTTON_DDR &= ~(1 << BUTTON_PIN);
    BUTTON_PORT |= (1 << BUTTON_PIN);  // pullup
}

static void fault_init(void) {
    FLTB_DDR &= ~(1 << FLTB_PIN);
    FLTB_PORT |= (1 << FLTB_PIN);  // pullup
}

static void fusb_int_init(void) {
    FUSB_INT_DDR &= ~(1 << FUSB_INT_PIN);
    FUSB_INT_PORT |= (1 << FUSB_INT_PIN);  // pullup
}

static bool button_is_pressed(void) {
    return !(BUTTON_PIN_REG & (1 << BUTTON_PIN));
}

static bool fault_is_active(void) {
    return !(FLTB_PIN_REG & (1 << FLTB_PIN));
}

static bool fusb_has_interrupt(void) {
    return !(FUSB_INT_PIN_REG & (1 << FUSB_INT_PIN));
}

// ========== VOLTAGE CYCLING & FALLBACK ==========
static uint8_t find_next_available_voltage(uint8_t start_idx) {
    for (uint8_t i = 0; i < N_VOLTAGES; i++) {
        uint8_t idx = (start_idx + 1 + i) % N_VOLTAGES;
        return idx;
    }
    return 0;
}

static void attempt_voltage_change(uint8_t new_idx) {
    if (new_idx >= N_VOLTAGES) return;
    
    current_voltage_idx = new_idx;
    
    if (!fusb_send_request(new_idx)) {
        leds_flash(2, 80);
        current_voltage_idx = find_next_available_voltage(new_idx);
    }
    
    leds_set(current_voltage_idx);
}

// ========== MAIN LOOP & INTERRUPT HANDLERS ==========
ISR(PCINT0_vect) {
    // portB changes: button (PB4) + i2c (PB0, PB1)
    static uint8_t btn_count = 0;
    if (button_is_pressed()) {
        btn_count++;
        if (btn_count >= 2) {
            button_pressed = true;
            btn_count = 0;
        }
    } else {
        btn_count = 0;
        button_release = true;
    }
}

ISR(PCINT1_vect) {
    // portC changes: FUSB INT (PC0) + FLTB (PC1)
    if (fusb_has_interrupt()) {
        fusb_interrupt = true;
    }
    if (fault_is_active()) {
        fault_detected = true;
    }
}

static void system_init(void) {
    cli();
    
    i2c_init();
    button_init();
    fault_init();
    fusb_int_init();
    leds_init();
    
    // Pin change interrupts
    PCMSK0 = (1 << PCINT4);  // Button on PB4
    PCMSK1 = (1 << PCINT8) | (1 << PCINT9);  // PC0 (FUSB INT) and PC1 (FLTB)
    GIMSK = (1 << PCIE0) | (1 << PCIE1);
    
    sei();
}

int main(void) {
    system_init();
    
    // Initialize FUSB302B
    if (!fusb_init()) {
        while (1) {
            leds_flash(5, 100);
            _delay_ms(500);
        }
    }
    
    // Request 5V on startup
    current_voltage_idx = 0;
    negotiated_voltage_idx = 0;
    attempt_voltage_change(0);
    
    while (1) {
        // Handle fault condition
        if (fault_detected) {
            fault_detected = false;
            leds_flash(3, 100);
            
            // Try to recover on current voltage
            uint8_t retry_count = 0;
            while (retry_count < 5 && fault_is_active()) {
                _delay_ms(200);
                fusb_send_request(current_voltage_idx);
                retry_count++;
            }
            
            if (fault_is_active()) {
                // If still faulted, try fallback
                current_voltage_idx = find_next_available_voltage(current_voltage_idx);
                attempt_voltage_change(current_voltage_idx);
            }
            continue;
        }
        
        // Handle button press
        if (button_pressed) {
            button_pressed = false;
            
            // Debounce
            _delay_ms(30);
            if (!button_is_pressed()) continue;
            
            // Cycle to next voltage
            uint8_t next_idx = (current_voltage_idx + 1) % N_VOLTAGES;
            attempt_voltage_change(next_idx);
            
            // Wait for release
            while (button_is_pressed()) {
                _delay_ms(10);
            }
            _delay_ms(30);
        }
        
        // Handle FUSB302 interrupt (PD events)
        if (fusb_interrupt) {
            fusb_interrupt = false;
            
            uint8_t int_status = 0;
            fusb_read_reg(FUSB_REG_INTERRUPT, &int_status);
        }
        
        _delay_ms(10);
    }
    
    return 0;
}

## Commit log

2026-02-10 Initial commit, PCB and Schem WIP
    [Charger_Kicad.kicad_pcb, Charger_Kicad.kicad_sch]
2026-02-11 Updated to use ISP5328P breakout, created initial case CAD
    [6S_Battery_Holder.SLDPRT, Battery_Cell.SLDPRT, Charger_Case.SLDPRT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]
2026-02-28 Created PD trigger mechanismx
    [Charger_Case_Top.SLDPRT, Charger_Main.SLDASM, USBC_PD_Trigger_Kicad.kicad_pcb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]
2026-03-02 Added V2 of trigger board w efuse and smaller mc
    [USBC_PD_Trigger_Kicad.kicad_pcb, USBC_PD_Trigger_Kicad.kicad_sch, USBC_PD_Trigger_Kicad_V2.kicad_pcb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]
2026-03-05 Updated Pd trigger to use only 1 cable
    [BOM-USBC_PD_Trigger_Kicad_V2.csv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]
2026-03-28 Added Code
    [6S_Battery_Holder.STL, Charger_Case.SLDPRT, Charger_Case.STL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]
